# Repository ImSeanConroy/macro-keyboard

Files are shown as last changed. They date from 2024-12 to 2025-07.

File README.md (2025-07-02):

# Minimal Layout, Maximum Efficiency

A collection of macro keyboards to boost your productivity without crowding your workspace.

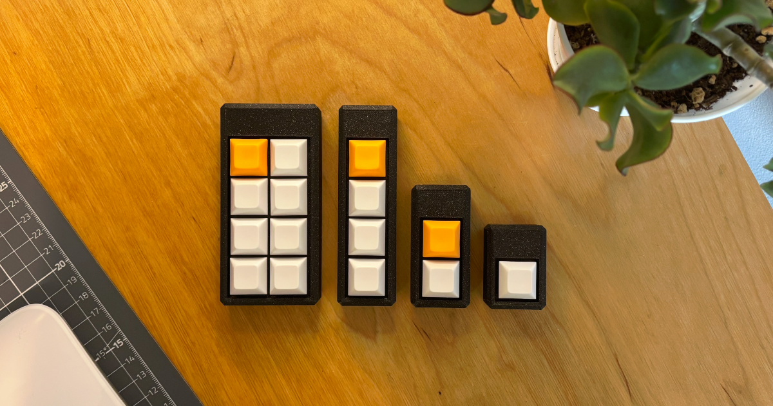
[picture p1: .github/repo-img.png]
Project Image


## Features and Development Roadmap

This project is considered complete for the time being, the following outlines the current features and potential future improvements:

### Current Features
- Compact Design: Space-saving with minimal desk footprint.
- Customizable Macros: Assign any key functions to match your workflow.
- Layout Variations: Supports various configurations (e.g., 1x1, 1x2, 1x4, 2x4, and 3x3).

### Future Improvements
- OLED Display: Add and test the inclusion of an OLED display.
- Bluetooth Functionality: Add and test wireless connectivity.
- Custom PCB Design: Move away from prebuilt Seeed Studio development boards. (A previous attempt was made, but limited electronics knowledge made debugging and identifying issues difficult.)

## Getting Started

1. **Open the Project** - Open the `.kicad_pro` file in KiCad to view the project.
2. **Review the Design** - Inspect the schematic and PCB layout to ensure it meets your needs.
3. **Customize or Export** - Make any modifications and export the Gerber files for fabrication.
4. **Order the PCB** - Submit the Gerber files to your preferred PCB manufacturer.
5. **Get the Components** - Purchase the components from the BOM and a compatible board.
6. **3D Print the Case** - Download the STL files for your chosen configuration and print them on a 3D printer.
7. **Assemble the Hardware** - Solder the components and assemble the board and case.
8. **Upload the Firmware** - Connect the board via USB and upload the firmware.

## Required Components

The following are the required components to build any of the macro keyboards:

| Quantity | Component | Description | Source |
| - | - | - | - |
| 1 | Seeed XIAO SAMD21 | Microcontroller board | [PiHut](https://thepihut.com/products/seeed-xiao-samd21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) |
| 12 | Kailh Mechanical Key Switches | Tactile switches | [PiHut](https://thepihut.com/products/kailh-mechanical-key-switches-linear-red-12-pack?variant=40151684677827) |
| 20 | Kailh Switch Sockets | For hot-swapping switches | [PiHut](https://thepihut.com/products/kailh-switch-sockets-for-mx-compatible-mechanical-keys-20-pack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) |
| 12 | White DSA Keycaps | Keycap set | [PiHut](https://thepihut.com/products/white-dsa-keycaps-for-mx-compatible-switches-10-pack?variant=40000301301955) |
| 12 | Orange DSA Keycaps | Keycap set | [PiHut](https://thepihut.com/products/orange-dsa-keycaps-for-mx-compatible-switches-10-pack?variant=40000347439299) |
| 10 | Neon Green DSA Keycaps | Keycap set | [PiHut](https://thepihut.com/products/neon-green-dsa-keycaps-for-mx-compatible-switches-10-pack?variant=40000348520643) |

## Contributing

Contributions are welcome. Please open an issue or submit a pull request for any enhancements or bug fixes.

## License

This project is Distributed under the MIT License - see the [LICENSE](LICENSE) file for information.

## Support

If you are having problems, please let me know by [raising a new issue](https://github.com/ImSeanConroy/macro-keyboard/issues/new/choose).

## Acknowledgments

This project was made possible thanks to the following resources:

- [Masterzen's Blog](https://www.masterzen.fr/) - Designing a keyboard from scratch
- [Keyboard Designer Wiki](https://wiki.ai03.com/books/pcb-design/chapter/pcb-designer-guide) - PCB Designer Guide 
- [Seeed Studio Wiki](https://wiki.seeedstudio.com/Seeeduino-XIAO/#resourses) - Getting Started with Seeed Studio XIAO SAMD21

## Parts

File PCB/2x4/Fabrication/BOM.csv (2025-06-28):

Id | Designator | Footprint | Quantity | Designation | Supplier and ref
1 | SW2,SW3,SW1,SW4,SW5,SW6,SW8,SW7 | MXOnly-1U-Hotswap | 8 | SW_Push | https://thepihut.com/products/kailh-switch-sockets-for-mx-compatible-mechanical-keys-20-pack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
2 | U2 | Seeeduino XIAO-MOUDLE14P-2.54-21X17.8MM | 1 | SeeeduinoXIAO | https://thepihut.com/products/seeed-xiao-samd21

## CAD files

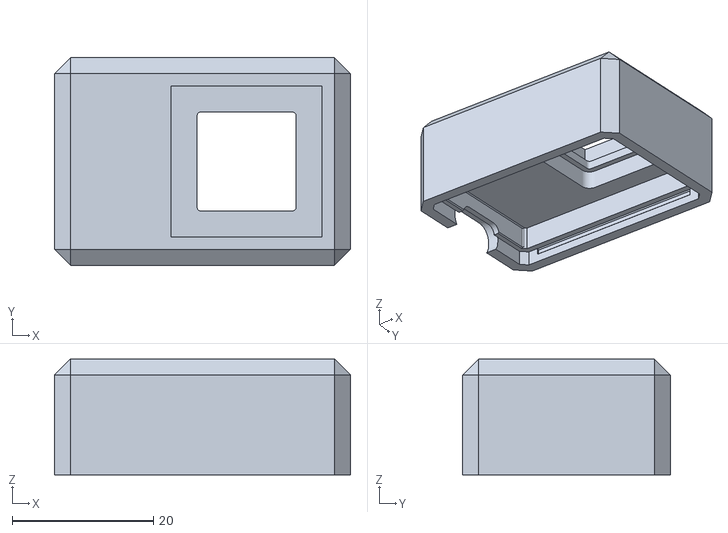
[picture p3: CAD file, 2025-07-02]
Case/1x1-upper.stl
41.9 x 29.4 x 16.4

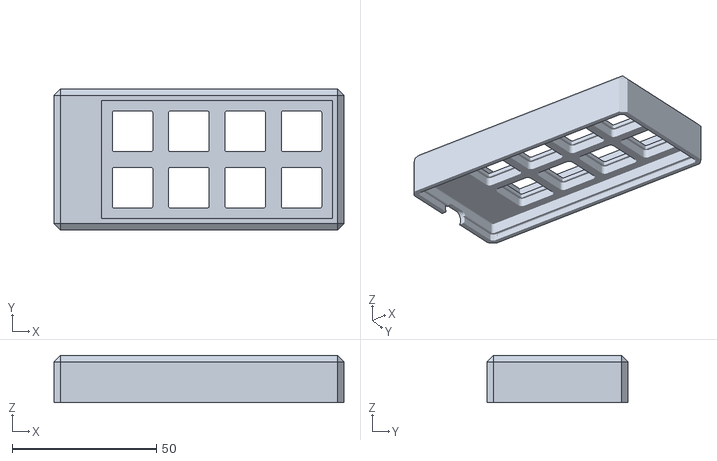
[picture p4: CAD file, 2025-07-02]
Case/2x4-upper.stl
100.4 x 48.9 x 16.4

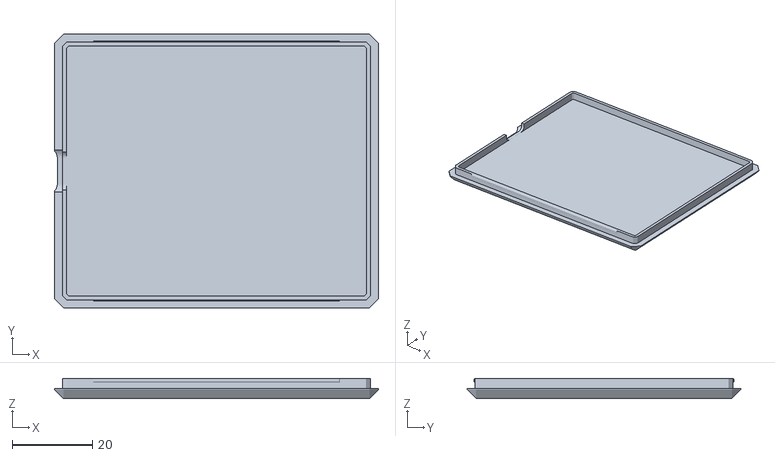
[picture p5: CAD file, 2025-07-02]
Case/3x3-lower.stl
80.9 x 68.4 x 5.00

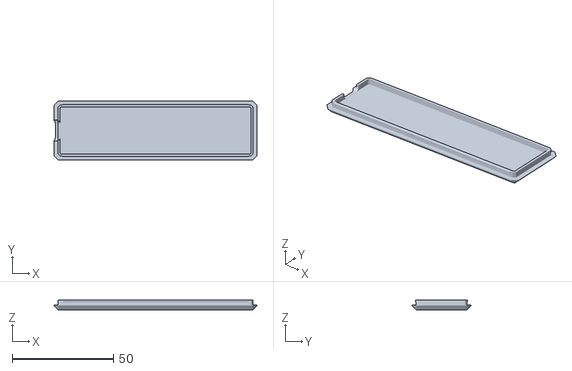
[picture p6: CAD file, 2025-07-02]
Case/1x4-lower.stl
100.4 x 29.4 x 5.00

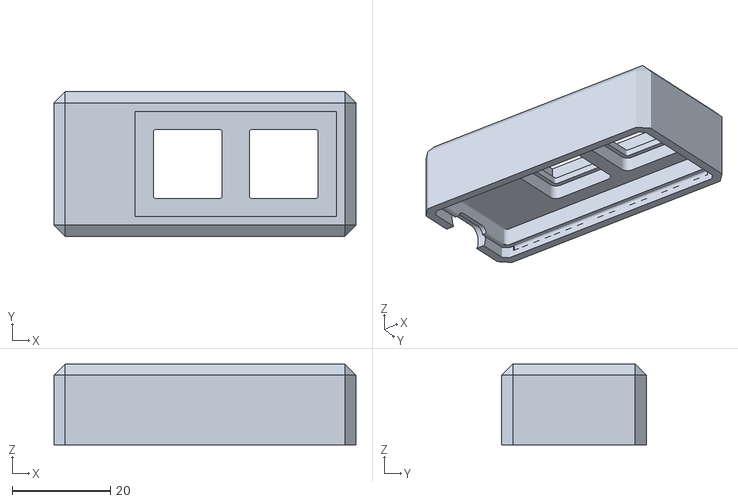
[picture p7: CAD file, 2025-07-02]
Case/1x2-upper.stl
61.4 x 29.4 x 16.4

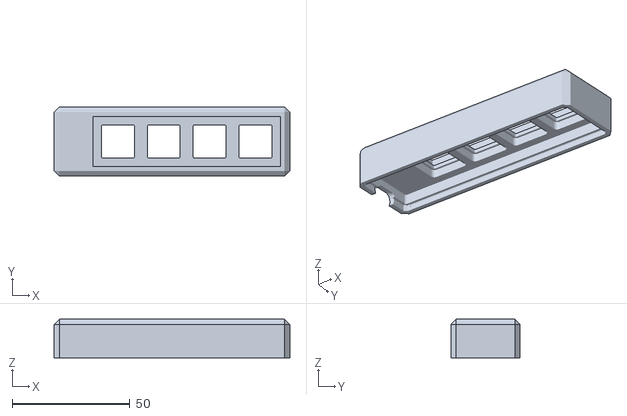
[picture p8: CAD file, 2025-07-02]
Case/1x4-upper.stl
100.4 x 29.4 x 16.4

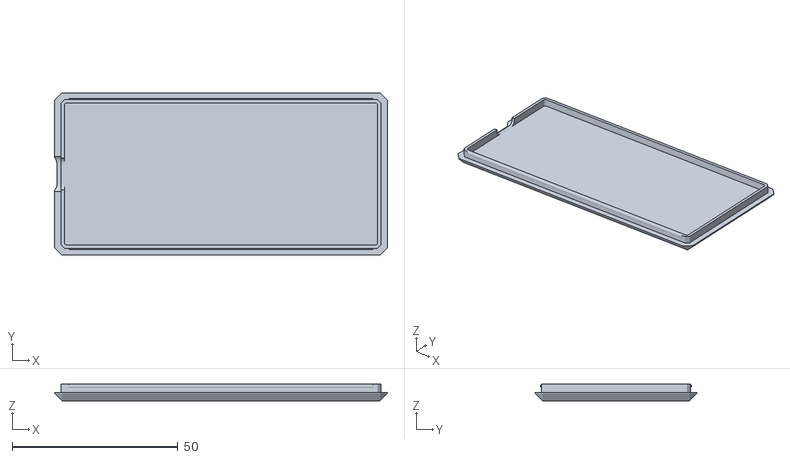
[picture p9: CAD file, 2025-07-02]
Case/2x4-lower.stl
100.4 x 48.9 x 5.00

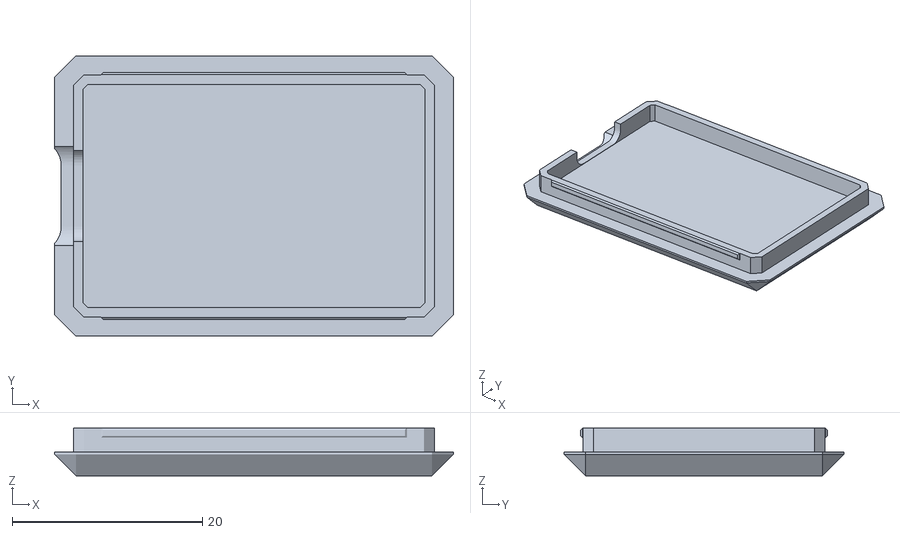
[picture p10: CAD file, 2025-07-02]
Case/1x1-lower.stl
41.9 x 29.4 x 5.00

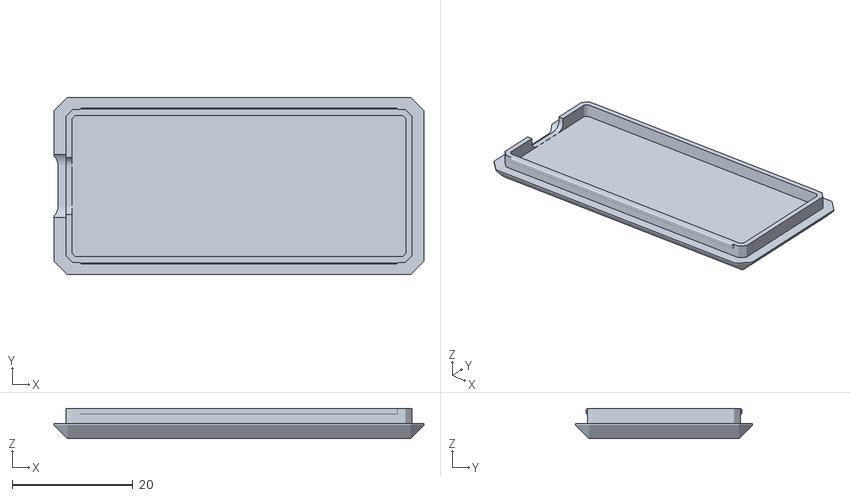
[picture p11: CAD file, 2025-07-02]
Case/1x2-lower.stl
61.4 x 29.4 x 5.00

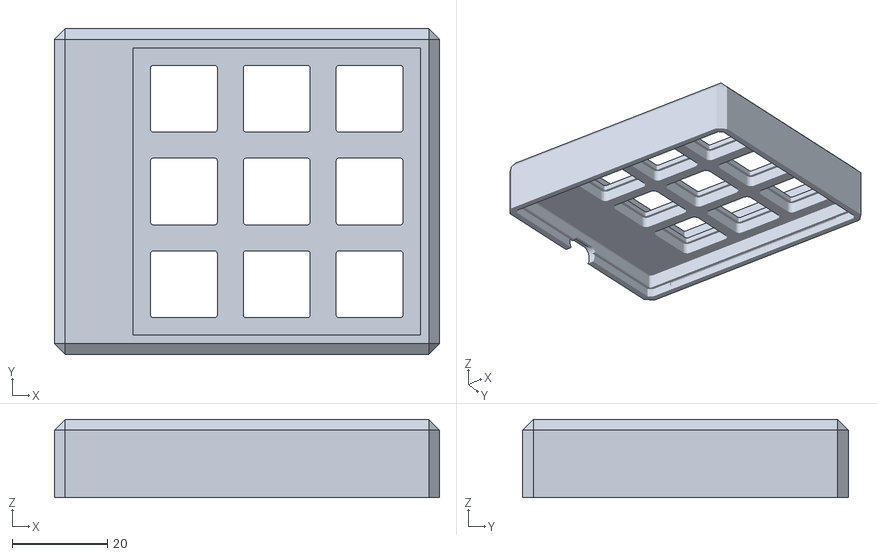
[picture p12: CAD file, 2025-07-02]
Case/3x3-upper.stl
80.9 x 68.4 x 16.4

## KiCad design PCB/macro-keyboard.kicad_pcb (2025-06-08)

Board: 2 copper layers, 5 parts (1 on the bottom side), 5 nets.

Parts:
SW1, SW2, SW3, SW4: SW_Push; MXOnly-1U-Hotswap
U1: MOUDLE-SEEEDUINO-XIAO-ESP32C3; MOUDLE14P-SMD-2.54-21X17.8MM

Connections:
GND: SW1.2, SW2.2, SW3.2, SW4.2, U1.13 (GND)
sw1: SW1.1, U1.1 (PA02_A0_D0)
sw2: SW2.1, U1.2 (PA4_A1_D1)
sw3: SW3.1, U1.3 (PA10_A2_D2)
sw4: SW4.1, U1.4 (PA11_A3_D3)

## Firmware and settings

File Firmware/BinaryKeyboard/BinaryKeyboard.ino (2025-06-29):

/*
 * ============================================================
 * Project: Macro Keyboard (Binary Keyboard - 1x2)
 * Developer: Sean Conroy
 * Board: Seeed XIAO SAMD21
 * License: MIT
 * Description:
 *   - Button 1 types binary 0
 *   - Button 2 types binary 1
 *   - After 8 bits are entered, converts to ASCII character and types it
 *   - Example: 01001000 01100101 01101100 01101100 01101111 00101100 00100000 01010111 01101111 01110010 01101100 01100100 00100001 00111111
 * ============================================================
 */

#include <Keyboard.h>

typedef void (*ButtonAction)();

struct Button {
  uint8_t pin;
  int currentState;
  int lastState;
  unsigned long lastDebounceTime;
  ButtonAction action;
};

String binaryBuffer = "";  // Store '0' and '1' presses

void typeChar(char c) {
  Keyboard.press(c);
  delay(5);
  Keyboard.release(c);
  delay(5);
}

void typeZero() {
  binaryBuffer += '0';
  checkBuffer();
}

void typeOne() {
  binaryBuffer += '1';
  checkBuffer();
}

void checkBuffer() {
  if (binaryBuffer.length() == 8) {
    // Convert binary string to char
    char c = (char) strtol(binaryBuffer.c_str(), nullptr, 2);

    // Type the ASCII char
    typeChar(c);

    // Clear buffer for next char
    binaryBuffer = "";
  }
}

Button buttons[] = {
  {0, HIGH, HIGH, 0, typeZero},
  {1, HIGH, HIGH, 0, typeOne},
};

const int NUM_BUTTONS = sizeof(buttons) / sizeof(buttons[0]);
const unsigned long DEBOUNCE_DELAY = 50;

void setup() {
  Keyboard.begin();
  for (int i = 0; i < NUM_BUTTONS; i++) {
    pinMode(buttons[i].pin, INPUT_PULLUP);
  }
}

void handleButton(Button &btn) {
  int reading = digitalRead(btn.pin);

  if (reading != btn.lastState) {
    btn.lastDebounceTime = millis();
  }

  if ((millis() - btn.lastDebounceTime) > DEBOUNCE_DELAY) {
    if (reading != btn.currentState) {
      btn.currentState = reading;

      if (btn.currentState == LOW && btn.action != nullptr) {
        btn.action();
      }
    }
  }

  btn.lastState = reading;
}

void loop() {
  for (int i = 0; i < NUM_BUTTONS; i++) {
    handleButton(buttons[i]);
  }
}

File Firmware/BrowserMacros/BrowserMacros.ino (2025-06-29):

/*
 * ============================================================
 * Project: Macro Keyboard (Browser Macros - 1x4)
 * Developer: Sean Conroy
 * Board: Seeed XIAO SAMD21
 * License: MIT
 * Description:
 *   - Button 1 opens GitHub (https://github.com)
 *   - Button 2 opens Google (https://google.com)
 *   - Button 3 opens YouTube (https://youtube.com)
 *   - Button 4 opens Twitch (https://twitch.tv)
 * ============================================================
 */

#include <Keyboard.h>

constexpr int URL_KEY_DELAY = 5;
constexpr int URL_COMMAND_DELAY = 100;

typedef void (*ButtonAction)();

struct Button {
  uint8_t pin;
  int currentState;
  int lastState;
  unsigned long lastDebounceTime;
  ButtonAction action;
};

void openUrl(const char *url) {
  const char *prefix = "https://";

  // Open new tab
  Keyboard.press(KEY_LEFT_GUI);
  Keyboard.press('t');
  delay(URL_COMMAND_DELAY);
  Keyboard.releaseAll();
  delay(URL_COMMAND_DELAY);

  // Focus browser address bar
  Keyboard.press(KEY_LEFT_GUI);
  Keyboard.press('l');
  delay(URL_COMMAND_DELAY);
  Keyboard.releaseAll();
  delay(URL_COMMAND_DELAY);

  // Type the URL prefix
  for (const char *p = prefix; *p; ++p) {
    Keyboard.press(*p);
    delay(URL_KEY_DELAY);
    Keyboard.release(*p);
    delay(URL_KEY_DELAY);
  }

  // Type the actual URL
  for (const char *p = url; *p; ++p) {
    Keyboard.press(*p);
    delay(URL_KEY_DELAY);
    Keyboard.release(*p);
    delay(URL_KEY_DELAY);
  }

  // Press Enter to go to the URL
  Keyboard.press(KEY_RETURN);
  delay(URL_COMMAND_DELAY);
  Keyboard.releaseAll();
}

void openGithub() {
  openUrl("github.com");
}

void openGoogle() {
  openUrl("google.com");
}

void openYoutube() {
  openUrl("youtube.com");
}

void openTwitch() {
  openUrl("twitch.tv");
}

Button buttons[] = {
  { 0, HIGH, HIGH, 0, openGithub },
  { 1, HIGH, HIGH, 0, openGoogle },
  { 2, HIGH, HIGH, 0, openYoutube },
  { 3, HIGH, HIGH, 0, openTwitch },
};

const int NUM_BUTTONS = sizeof(buttons) / sizeof(buttons[0]);
const unsigned long DEBOUNCE_DELAY = 50;

void setup() {
  Keyboard.begin();
  for (int i = 0; i < NUM_BUTTONS; i++) {
    pinMode(buttons[i].pin, INPUT_PULLUP);
  }
}

void handleButton(Button &btn) {
  int reading = digitalRead(btn.pin);

  if (reading != btn.lastState) {
    btn.lastDebounceTime = millis();
  }

  if ((millis() - btn.lastDebounceTime) > DEBOUNCE_DELAY) {
    if (reading != btn.currentState) {
      btn.currentState = reading;

      if (btn.currentState == LOW && btn.action != nullptr) {
        btn.action();
      }
    }
  }

  btn.lastState = reading;
}

void loop() {
  for (int i = 0; i < NUM_BUTTONS; i++) {
    handleButton(buttons[i]);
  }
}

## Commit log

2024-11-15 Setup kicad project
    [macro-keyboard.kicad_pcb, macro-keyboard.kicad_sch]
2024-11-16 Create schematic
    [macro-keyboard.kicad_pcb, macro-keyboard.kicad_sch]
2024-11-18 Update footprint and symbol references
    [macro-keyboard.kicad_pcb]
2024-12-30 Layout keycaps
    [macro-keyboard.kicad_pcb, macro-keyboard.kicad_sch]
2024-12-31 Layout traces and remove isp header and fours keys
    [macro-keyboard.kicad_pcb, macro-keyboard.kicad_sch]
2025-01-09 Update models and add mounting holes
    [macro-keyboard.kicad_pcb, macro-keyboard.kicad_sch]
2025-01-13 Add work in progress case for 2x4
    [2x4-lower-wip.step, 2x4-upper-wip.step]
2025-01-14 Improve case and convert file to stl
    [2x4-lower-wip.step, 2x4-lower.stl, 2x4-upper-wip.step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]
2025-01-18 Add gerber files
    [macro-keyboard-B_Cu.gbr, macro-keyboard-B_Mask.gbr, macro-keyboard-B_Paste.gbr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]
2025-01-22 Add boxes to schematic
    [macro-keyboard.kicad_pcb, macro-keyboard.kicad_sch]
2025-02-06 Add missing decoupling capacitor
    [macro-keyboard-B_Cu.gbr, macro-keyboard-B_Mask.gbr, macro-keyboard-B_Paste.gbr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]
2025-02-07 Convert to 4 layer board and update traces
    [macro-keyboard.kicad_pcb]
2025-06-08 Significantly simplify design
    [macro-keyboard-B_Cu.gbr, macro-keyboard-B_Mask.gbr, macro-keyboard-B_Paste.gbr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]
2025-06-20 Convert to use seeed studio xiao samd21
    [macro-keyboard.kicad_sch]
2025-06-21 Update case for simplified design
    [2x4-lower.stl, 2x4-upper.stl, 4x1-lower.stl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]
2025-06-22 Add varied case configurations
    [1x1-lower.stl, 1x1-upper.stl, 2x1-lower.stl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]
2025-06-27 Add 1x1 and 1x2 pcb design files
    [1x1-B_Cu.gbr, 1x1-B_Mask.gbr, 1x1-B_Paste.gbr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]
2025-06-28 Add 2x4 and 3x3 pcb design files
    [1x1-B_Cu.gbr, 1x1-B_Mask.gbr, 1x1-B_Paste.gbr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]
2025-07-02 Fix case usb issue
    [1x1-lower.stl, 1x1-upper.stl, 1x2-lower.stl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]
